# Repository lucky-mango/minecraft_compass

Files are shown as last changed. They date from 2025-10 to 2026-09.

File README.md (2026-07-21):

# Minecraft Compass — Digital Build

This repo documents my journey building a digital compass inspired by Minecraft, using an LED matrix PCB inside a custom 3D-printed enclosure.

## Preview

### FreeCAD design

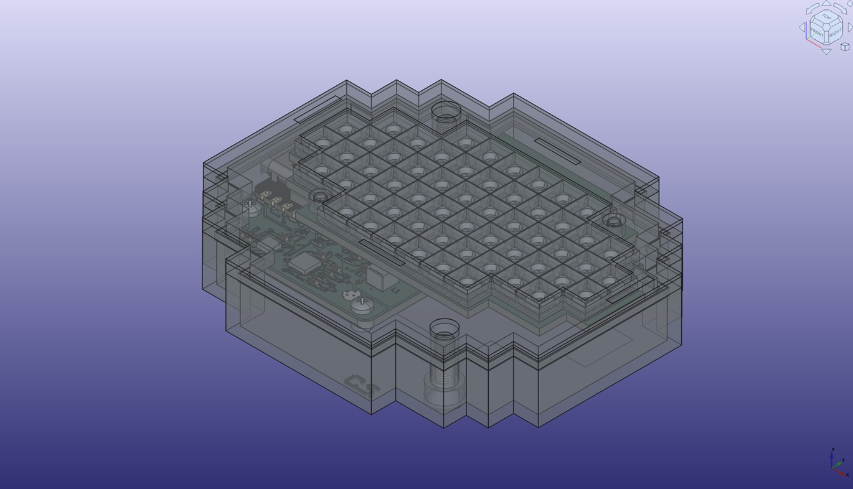
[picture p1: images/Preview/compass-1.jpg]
compass-1

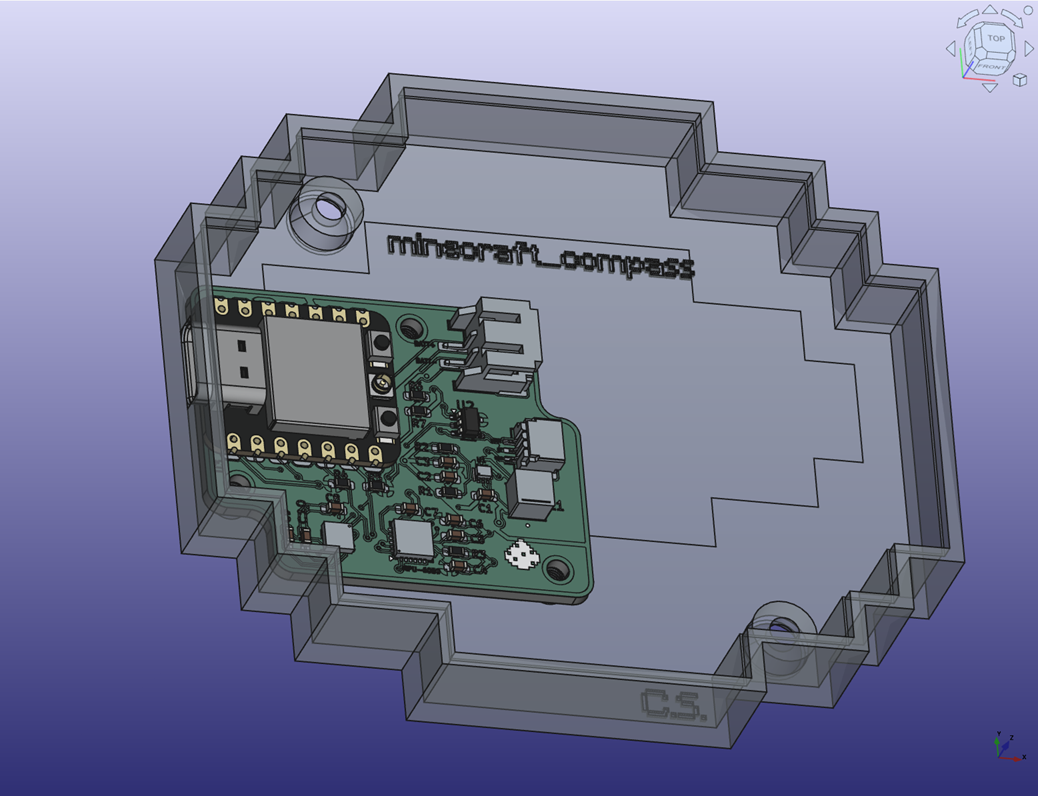
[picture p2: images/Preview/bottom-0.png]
bottom-0

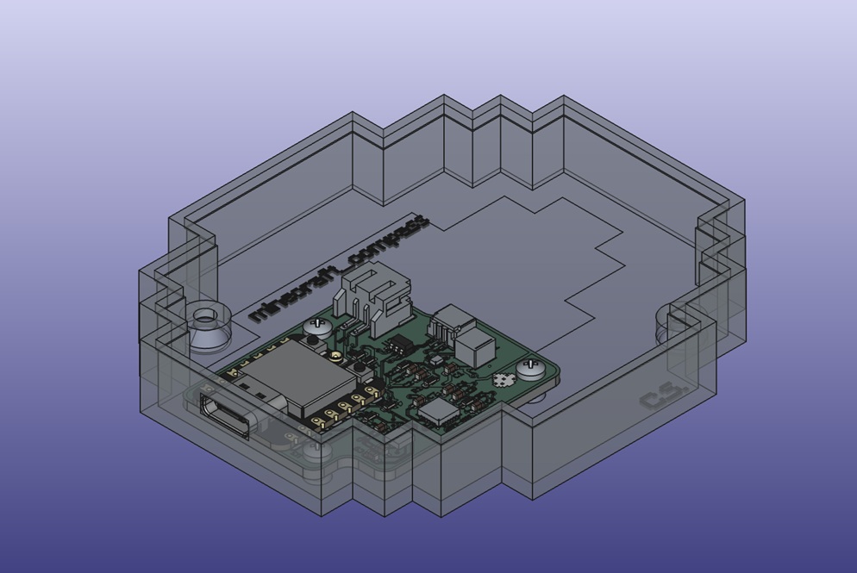
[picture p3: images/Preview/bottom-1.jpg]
bottom-1

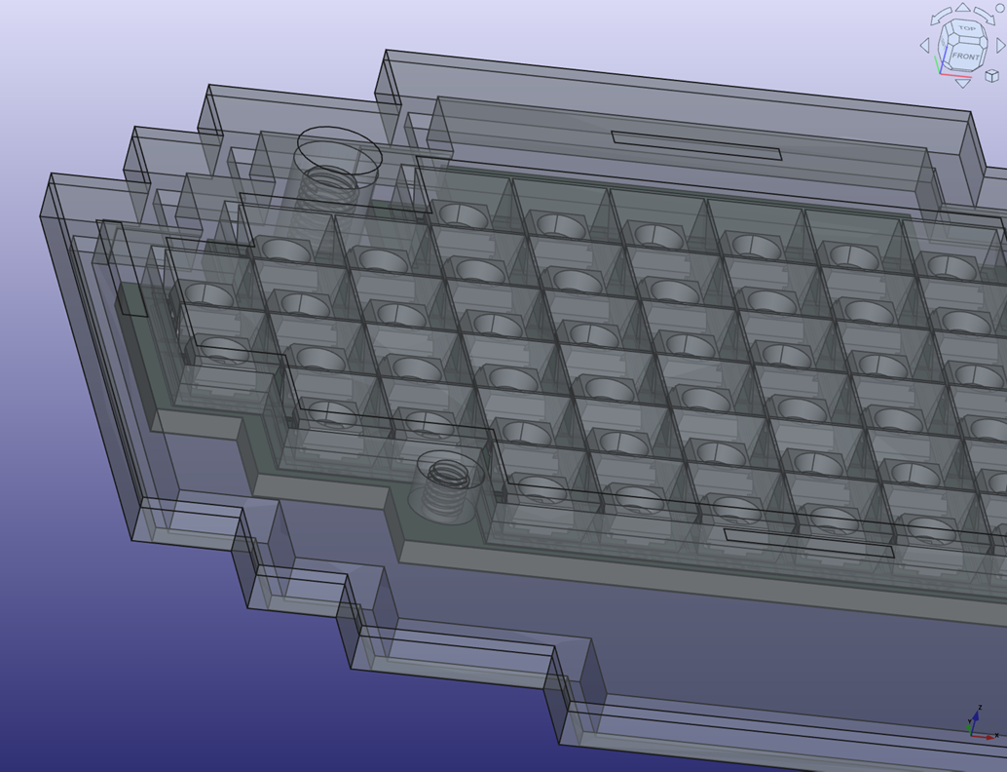
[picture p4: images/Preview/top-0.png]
top-0


### KiCAD design

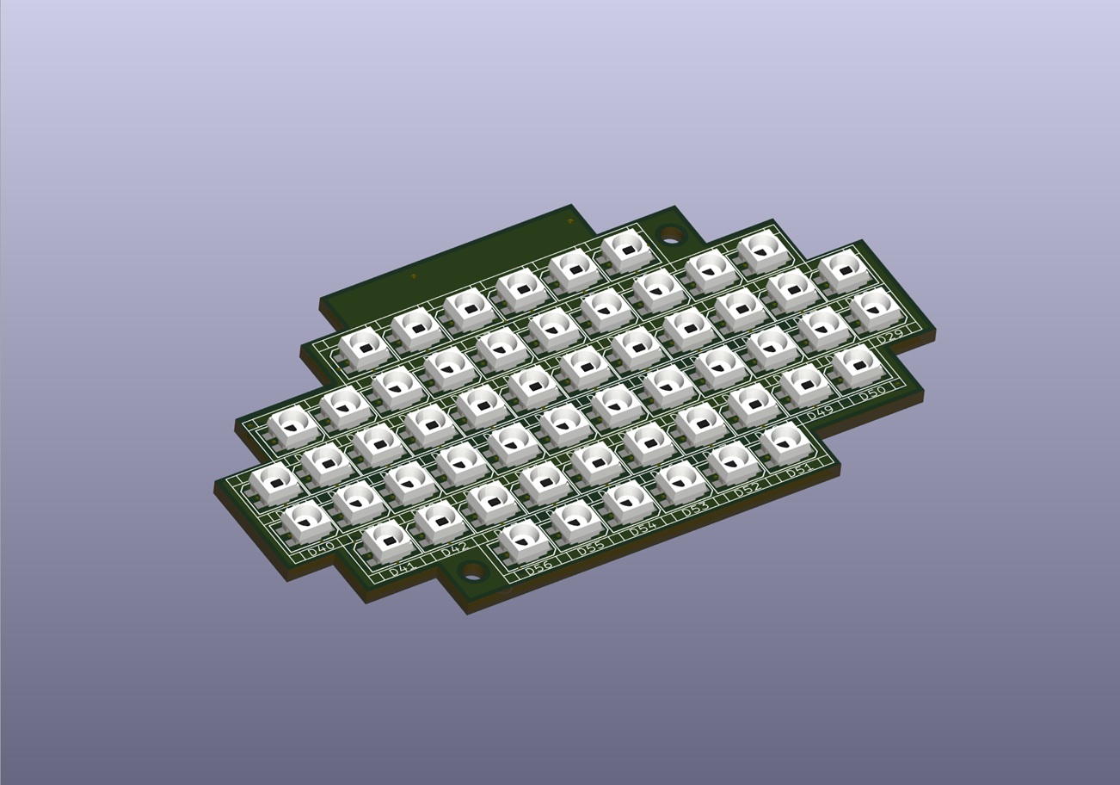
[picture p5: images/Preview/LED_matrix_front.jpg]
LED_matrix_front

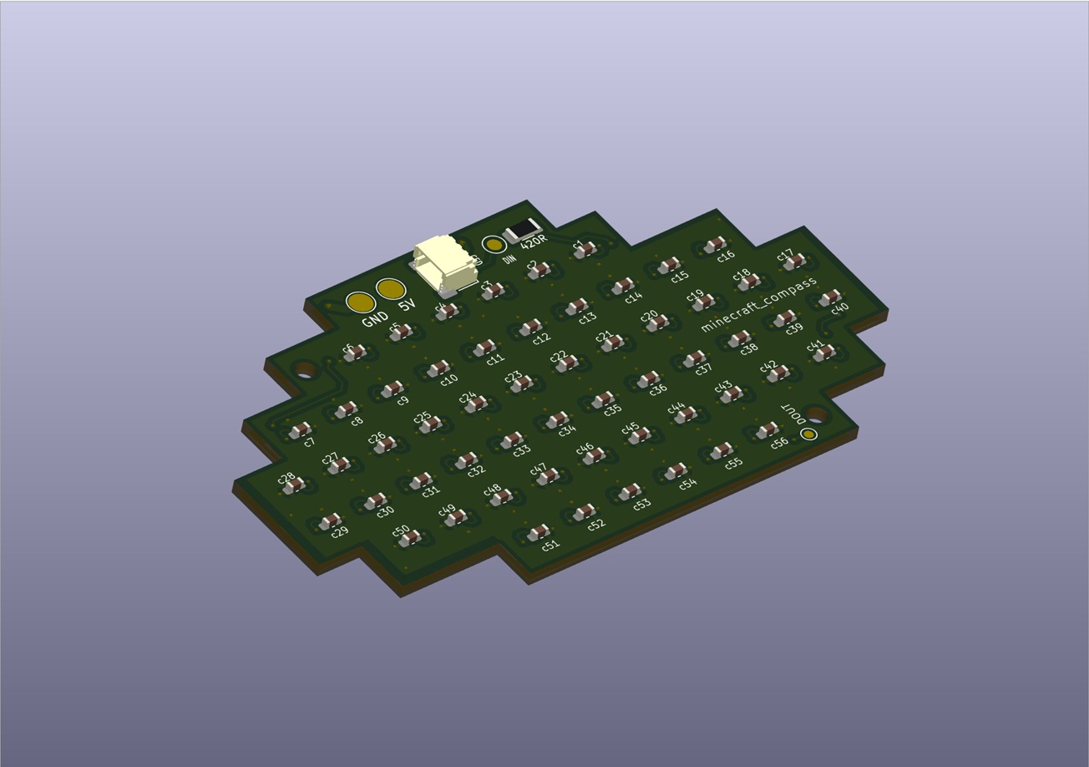
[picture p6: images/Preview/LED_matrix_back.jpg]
LED_matrix_back

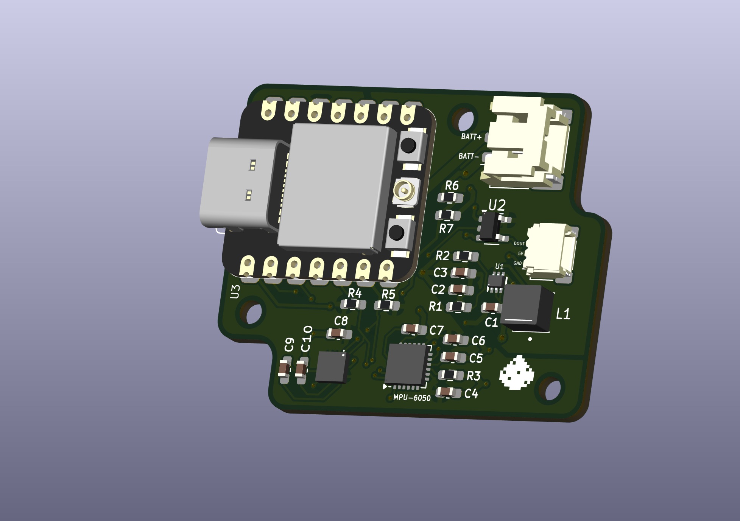
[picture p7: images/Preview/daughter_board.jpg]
daughter_board


## Repository Structure

| Path | Contents |
| --- | --- |
| `STL/` | 3D-printable enclosure files. Subdirectories (`ver1`–`ver9`) track design iterations; the latest is in `STL/ver9/`. |
| `KiCAD/Clone-new_ledMatrix/` | Current KiCAD PCB project (schematic, layout, and Gerber exports). |
| `KiCAD/new_ledMatrix/` | Earlier KiCAD project kept for reference. |
| `FreeCAD/` | FreeCAD source models for the enclosure. |
| `PCB/` | Fabrication-ready Gerber ZIP files for ordering the PCB. |
| `test_code/` | Firmware and animation test sketches. |
| `datasheets/` | Component datasheets (e.g. WS2812B-MINI LED). |
| `images/` | Project screenshots and reference images. |

## 3D Printing the Enclosure

The current STL files are in [`STL/ver9/`](STL/ver9/). Import them into your slicer (e.g. PrusaSlicer or Cura) and print as-is — no supports should be required.

## Prior Design Iterations

All previous versions of every file are preserved in Git history. Browse the [commit history](../../commits/main) on GitHub or run `git log` locally to find and restore any earlier iteration.

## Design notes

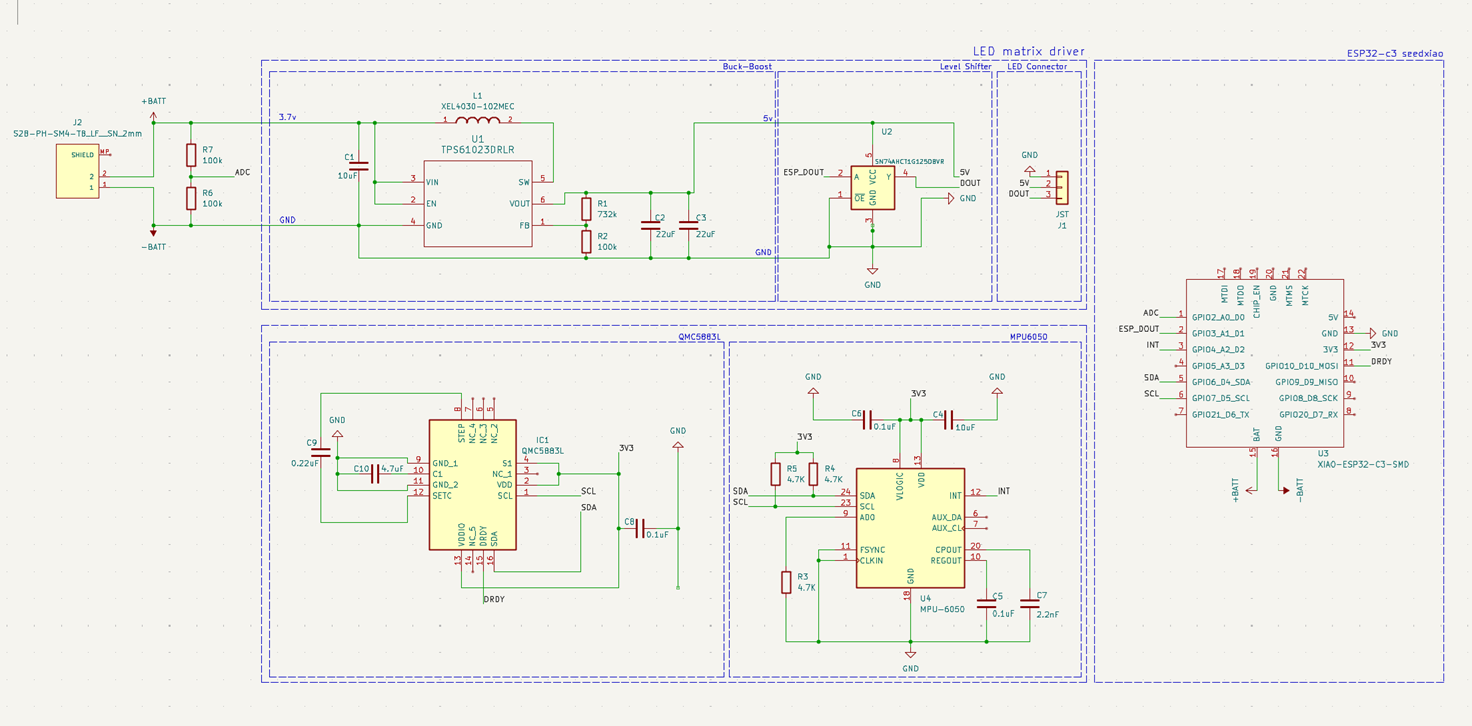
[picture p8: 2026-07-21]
images/Preview/schematic.png

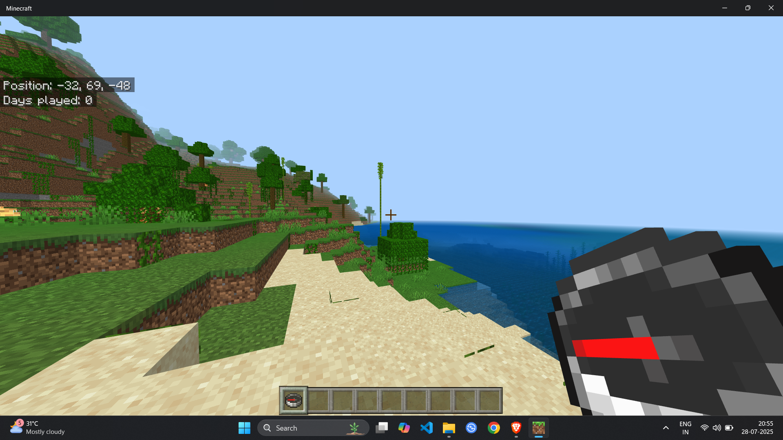
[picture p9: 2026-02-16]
images/inGame/Screenshot (229).png

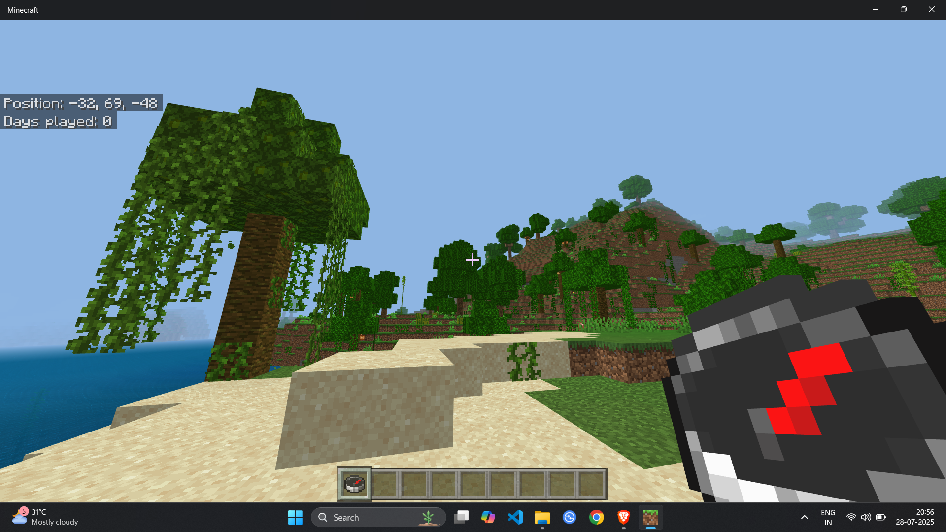
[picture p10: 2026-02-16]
images/inGame/Screenshot (245).png

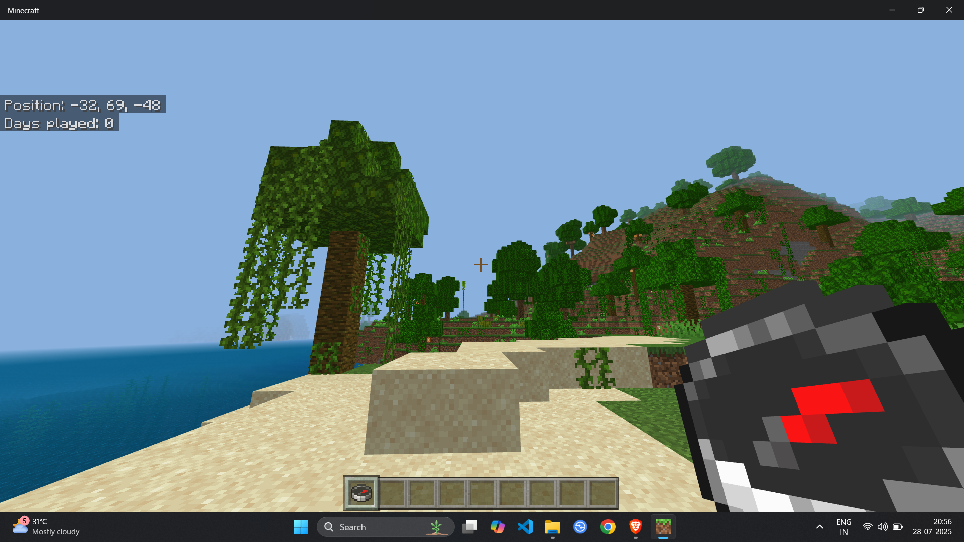
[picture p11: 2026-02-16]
images/inGame/Screenshot (244).png

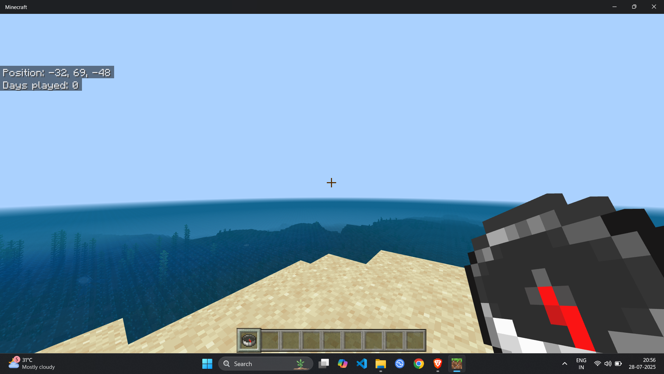
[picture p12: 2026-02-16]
images/inGame/Screenshot (236).png

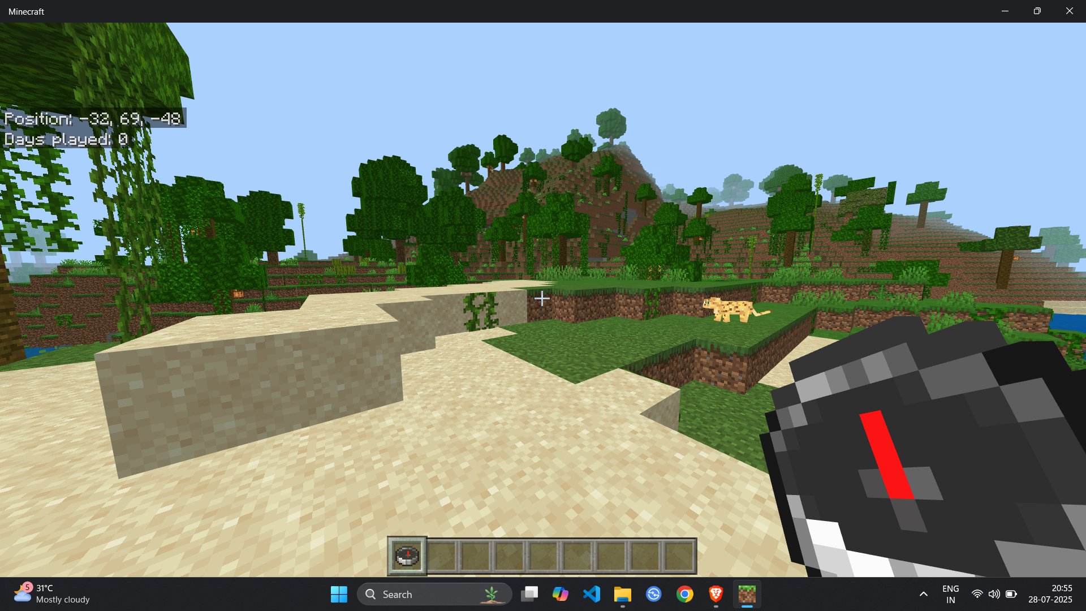
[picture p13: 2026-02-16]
images/inGame/Screenshot (222).png

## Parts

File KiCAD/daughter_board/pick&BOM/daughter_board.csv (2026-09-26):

SKU | MPN | Qty | Footprint | Reference | Value | DNP | Exclude from BOM | Exclude from Board | Datasheet
162123 |  | 1 | Sensor_Motion:InvenSense_QFN-24_4x4mm_P0.5mm_NoMask | U4 | MPU-6050 |  |  |  | https://invensense.tdk.com/wp-content/uploads/2015/02/MPU-6000-Datasheet1.pdf
 |  | 1 | My_Custom_Footprints:XIAO-ESP32C3-SMD | U3 | XIAO-ESP32-C3-SMD
R201770 | SN74AHCT1G125DBVR | 1 | Package_TO_SOT_SMD:SOT-23-5 | U2 | SN74AHCT1G125DBVR |  |  |  | https://www.onsemi.com/pdf/datasheet/nc7sz125-d.pdf
R216425 | TPS61023DRLR | 1 | custom_lib:TPS61023DRLR | U1 | TPS61023DRLR |  |  |  | https://www.ti.com/lit/gpn/tps61023
R209018 | CRCW0603100KFKEAC. | 1 | Resistor_SMD:R_0603_1608Metric | R7 | 100k |  |  |  | ~
R209018 | CRCW0603100KFKEAC | 1 | Resistor_SMD:R_0603_1608Metric | R6 | 100k |  |  |  | ~
573846 |  | 1 | Resistor_SMD:R_0603_1608Metric | R5 | 4.7K |  |  |  | ~
573846 |  | 1 | Resistor_SMD:R_0603_1608Metric | R4 | 4.7K |  |  |  | ~
573846 |  | 1 | Resistor_SMD:R_0603_1608Metric | R3 | 4.7K |  |  |  | ~
R209018 | CRCW0603100KFKEAC | 1 | Resistor_SMD:R_0603_1608Metric | R2 | 100k |  |  |  | ~
R197181 | RC0603FR-07732KL | 1 | Resistor_SMD:R_0603_1608Metric | R1 | 732k |  |  |  | ~
R113961 | XFL4020-222MEC | 1 | custom_lib:IND_XEL4030-102MEC | L1 | XEL4030-102MEC
R136185 | WT100EW-02-0-T-00 | 1 |  | J3 | SM02B-SRSS-TB_LF__SN_
R136189 | WT100EL-03-T-00 | 1 | Connector_JST:JST_SH_SM03B-SRSS-TB_1x03-1MP_P1.00mm_Horizontal | J1 | JST |  |  |  | ~
 | QMC5883L | 1 | custom_lib:QMC5883L | IC1 | QMC5883L |  |  |  | https://datasheet.lcsc.com/lcsc/2012221837_QST-QMC5883L_C976032.pdf
R144123 | CL10A475MA8NQNC | 1 | Capacitor_SMD:C_0603_1608Metric | C10 | 4.7uF |  |  |  | ~
R144018 | GRM155R71C224MA12D | 1 | Capacitor_SMD:C_0603_1608Metric | C9 | 0.22uF |  |  |  | ~
1415725 |  | 1 | Capacitor_SMD:C_0603_1608Metric | C8 | 0.1uF |  |  |  | ~
R207408 | 0603B222K500NT | 1 | Capacitor_SMD:C_0603_1608Metric | C7 | 2.2nF |  |  |  | ~
1415725 |  | 1 | Capacitor_SMD:C_0603_1608Metric | C6 | 0.1uF |  |  |  | ~
1415725 |  | 1 | Capacitor_SMD:C_0603_1608Metric | C5 | 0.1uF |  |  |  | ~
R144118 | 0603X106K160NT | 1 | Capacitor_SMD:C_0603_1608Metric | C4 | 10uF |  |  |  | ~
R243185 | CL10A226MO7JZNC | 1 | Capacitor_SMD:C_0603_1608Metric | C3 | 22uF |  |  |  | ~
R243185 | CL10A226MO7JZNC | 1 | Capacitor_SMD:C_0603_1608Metric | C2 | 22uF |  |  |  | ~
R144118 | 0603X106K160NT | 1 | Capacitor_SMD:C_0603_1608Metric | C1 | 10uF |  |  |  | ~

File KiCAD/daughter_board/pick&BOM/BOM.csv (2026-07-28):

Id | Designator | Footprint | Quantity | Designation | Supplier and ref
1 | U2 | SOT-23-5 | 1 | SN74AHCT1G125DBVR
2 | U1 | TPS61023DRLR | 1 | TPS61023DRLR
3 | U3 | XIAO-ESP32C3-SMD | 1 | XIAO-ESP32-C3-SMD
4 | C6,C8,C5 | C_0603_1608Metric_Pad1.08x0.95mm_HandSolder | 3 | 0.1uF
5 | R2,R7,R6 | R_0603_1608Metric_Pad0.98x0.95mm_HandSolder | 3 | 100k
6 | 0.8mm | Castellated_Hole_0.8mm | 1 | Castellated_Hole_0.8mm
7 | C1,C4 | C_0603_1608Metric_Pad1.08x0.95mm_HandSolder | 2 | 10uF
8 | J1 | JST_SH_SM03B-SRSS-TB_1x03-1MP_P1.00mm_Horizontal | 1 | JST
9 | C3,C2 | C_0603_1608Metric_Pad1.08x0.95mm_HandSolder | 2 | 22uF
10 | R5,R3,R4 | R_0603_1608Metric_Pad0.98x0.95mm_HandSolder | 3 | 4.7K
11 | C10 | C_0603_1608Metric_Pad1.08x0.95mm_HandSolder | 1 | 4.7uF
12 | R1 | R_0603_1608Metric_Pad0.98x0.95mm_HandSolder | 1 | 732k
13 | L1 | IND_XEL4030-102MEC | 1 | XEL4030-102MEC
14 | C9 | C_0603_1608Metric_Pad1.08x0.95mm_HandSolder | 1 | 0.22uF
15 | U4 | InvenSense_QFN-24_4x4mm_P0.5mm_NoMask | 1 | MPU-6050
16 | J2 | JST_PH_S2B-PH-SM4-TB_1x02-1MP_P2.00mm_Horizontal | 1 | S2B-PH-SM4-TB_LF__SN_2mm
17 | IC1 | QMC5883L | 1 | QMC5883L
18 |  |  | 1
19 | C7 | C_0603_1608Metric_Pad1.08x0.95mm_HandSolder | 1 | 2.2nF

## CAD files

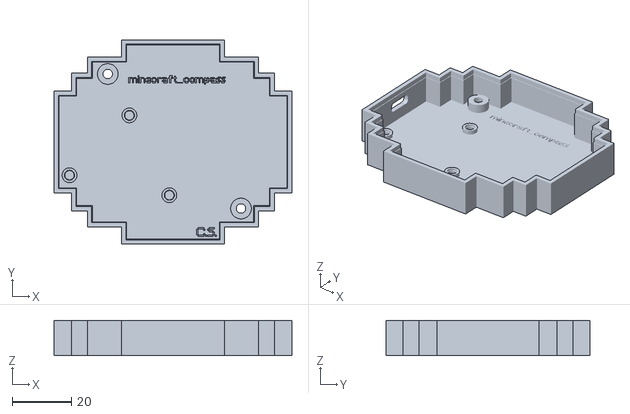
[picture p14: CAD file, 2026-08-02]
3D_models/compass_case/minecraftCompassVer.4-bottom_plate(lowered_daughterBoard,heatinserts-2mm_deep).stl
80.5 x 69.1 x 12.0

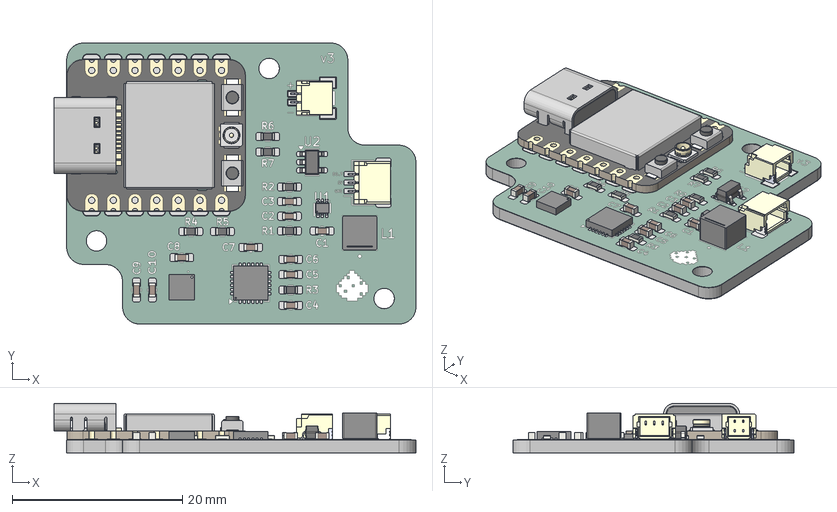
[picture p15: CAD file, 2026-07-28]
3D_models/daughter_board-v3.step
42.5 x 33.0 x 5.88 mm
SOT-23-5
TPS61023DRLR
BOSS-EXTRUDE14_8_
BOSS-EXTRUDE7_4_
BOSS-EXTRUDE7_3_
BOSS-EXTRUDE14_4_
BOSS-EXTRUDE14_2_
BOSS-EXTRUDE14_11_
BOSS-EXTRUDE7_7_
BOSS-EXTRUDE14_9_
BOSS-EXTRUDE14_3_
BOSS-EXTRUDE14_7_
MIRROR2
BOSS-EXTRUDE14_5_
BOSS-EXTRUDE14_12_
BOSS-EXTRUDE7_8_
BOSS-EXTRUDE7_1_
BOSS-EXTRUDE14_10_
BOSS-EXTRUDE7_9_
BOSS-EXTRUDE14_6_
BOSS-EXTRUDE14_1_
BOSS-EXTRUDE7_6_
BOSS-EXTRUDE7_2_
CUT-EXTRUDE5
BOSS-EXTRUDE7_5_
U.FL Connector v1
Button (1) x 2
Shield
C_0603_1608Metric x 10
R_0603_1608Metric x 7
SM03B-SRSS-TB (LF)(SN)
SM02B-SRSS-TB_LF__SN_
XEL4030-102MEC--3DModel-STEP-269445
MPU-6050C
HMC5883L-TR
daughter_board_copper
daughter_board_pad
daughter_board_via
daughter_board_silkscreen
daughter_board_soldermask
daughter_board_PCB

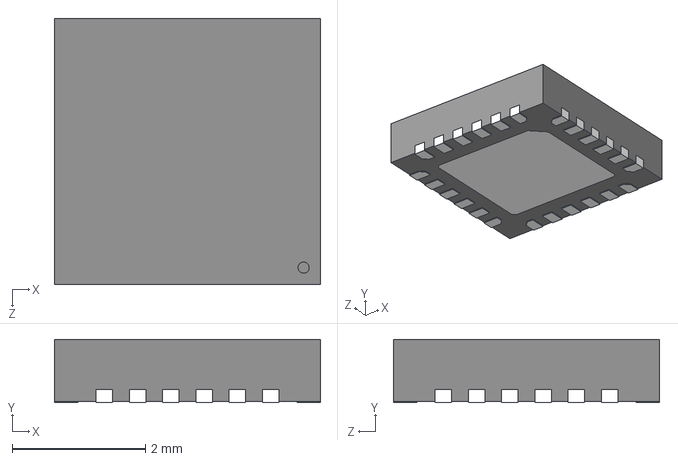
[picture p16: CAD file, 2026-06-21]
3D_models/mpu6050-8.snapshot.1/MPU-6050C.STEP
4.00 x 0.95 x 4.00 mm

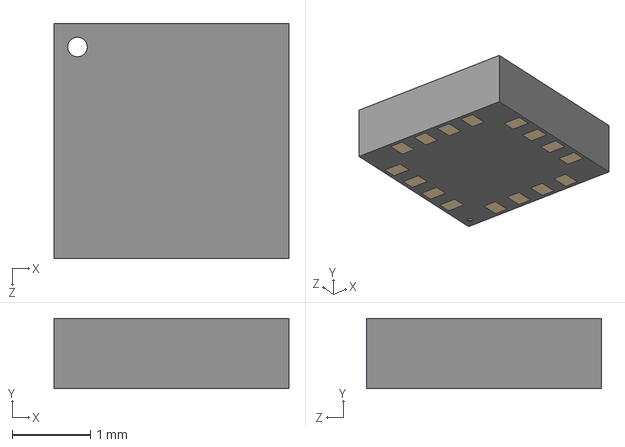
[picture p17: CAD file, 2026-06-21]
3D_models/QMC5883L/3D/HMC5883L-TR.STEP
3.00 x 0.9 x 3.00 mm

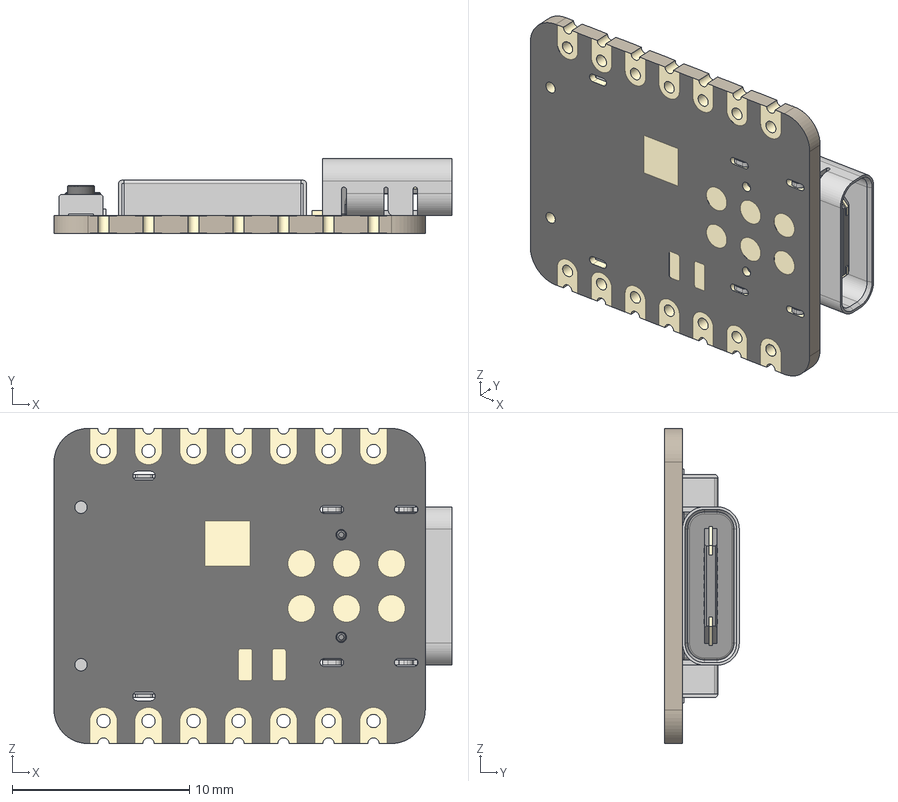
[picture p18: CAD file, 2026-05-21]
3D_models/seeed-studio-xiao-esp32-c3-1.snapshot.8 (1)/Seeed Studio XIAO-ESP32-C3.step
22.5 x 4.21 x 17.8 mm
BOSS-EXTRUDE14_8_
BOSS-EXTRUDE7_4_
BOSS-EXTRUDE7_3_
BOSS-EXTRUDE14_4_
BOSS-EXTRUDE14_2_
BOSS-EXTRUDE14_11_
BOSS-EXTRUDE7_7_
BOSS-EXTRUDE14_9_
BOSS-EXTRUDE14_3_
BOSS-EXTRUDE14_7_
MIRROR2
BOSS-EXTRUDE14_5_
BOSS-EXTRUDE14_12_
BOSS-EXTRUDE7_8_
BOSS-EXTRUDE7_1_
BOSS-EXTRUDE14_10_
BOSS-EXTRUDE7_9_
BOSS-EXTRUDE14_6_
BOSS-EXTRUDE14_1_
BOSS-EXTRUDE7_6_
BOSS-EXTRUDE7_2_
CUT-EXTRUDE5
BOSS-EXTRUDE7_5_
U.FL Connector v1
Button (1) x 2
Shield

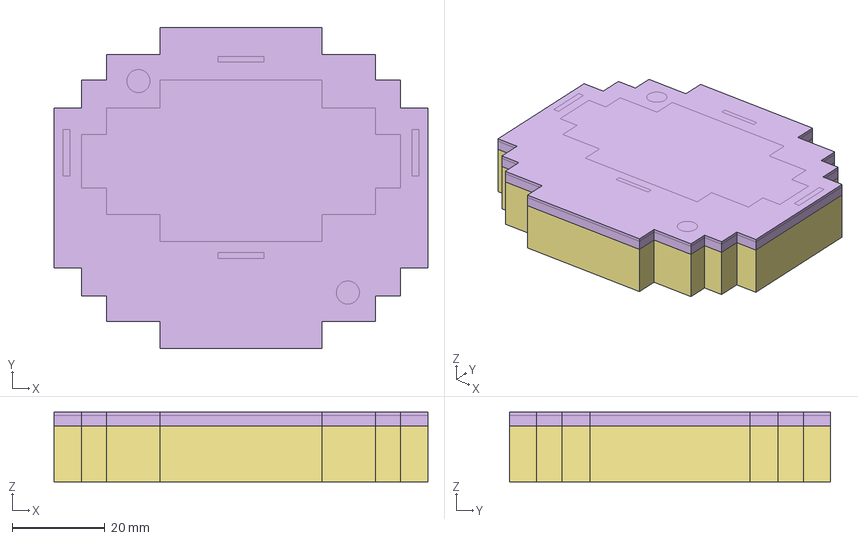
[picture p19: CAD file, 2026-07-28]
FreeCAD/minecraftCompassVer.4.FCStd
80.5 x 69.1 x 15.0 mm
M2x4-Screw001
M2x4-Screw
M2x3-Screw050
M2x3-Screw049
M2x3-Screw
top_plate
bottom_plate
SMD WS2812B Mini
SMD WS2812B Mini001
SMD WS2812B Mini002
SMD WS2812B Mini003
SMD WS2812B Mini004
SMD WS2812B Mini005
SMD WS2812B Mini006
SMD WS2812B Mini007
SMD WS2812B Mini008
SMD WS2812B Mini009
SMD WS2812B Mini010
SMD WS2812B Mini011
SMD WS2812B Mini012
SMD WS2812B Mini013
SMD WS2812B Mini014
SMD WS2812B Mini015
SMD WS2812B Mini016
SMD WS2812B Mini017
SMD WS2812B Mini018
SMD WS2812B Mini019
SMD WS2812B Mini020
SMD WS2812B Mini021
SMD WS2812B Mini022
SMD WS2812B Mini023
SMD WS2812B Mini024
SMD WS2812B Mini025
SMD WS2812B Mini026
SMD WS2812B Mini027
SMD WS2812B Mini028
SMD WS2812B Mini029
SMD WS2812B Mini030
SMD WS2812B Mini031
SMD WS2812B Mini032
SMD WS2812B Mini033
SMD WS2812B Mini034
SMD WS2812B Mini035
SMD WS2812B Mini036
SMD WS2812B Mini037
SMD WS2812B Mini038
SMD WS2812B Mini039
SMD WS2812B Mini040
SMD WS2812B Mini041
SMD WS2812B Mini042
SMD WS2812B Mini043
SMD WS2812B Mini044
SMD WS2812B Mini045
SMD WS2812B Mini046
SMD WS2812B Mini047
SMD WS2812B Mini048
SMD WS2812B Mini049
SMD WS2812B Mini050
SMD WS2812B Mini051
SMD WS2812B Mini052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

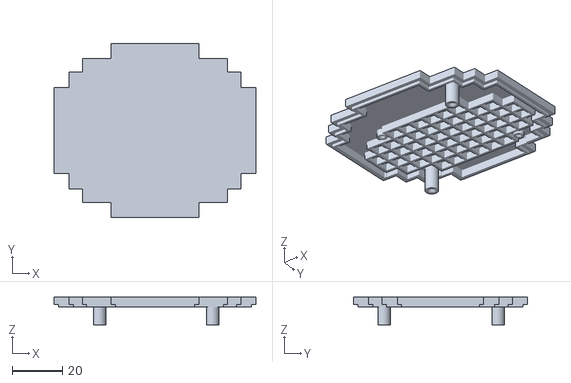
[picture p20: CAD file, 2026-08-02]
3D_models/compass_case/minecraftCompassVer.4-bottom_plate(4mm_gridBezzel).stl
80.5 x 69.1 x 11.0

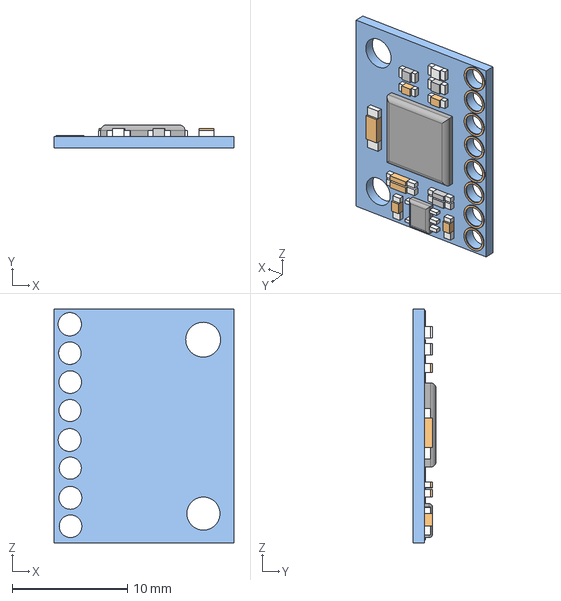
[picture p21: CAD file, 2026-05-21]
3D_models/mpu6050-8.snapshot.1/MPU6050 v2.step
15.6 x 2.00 x 20.3 mm

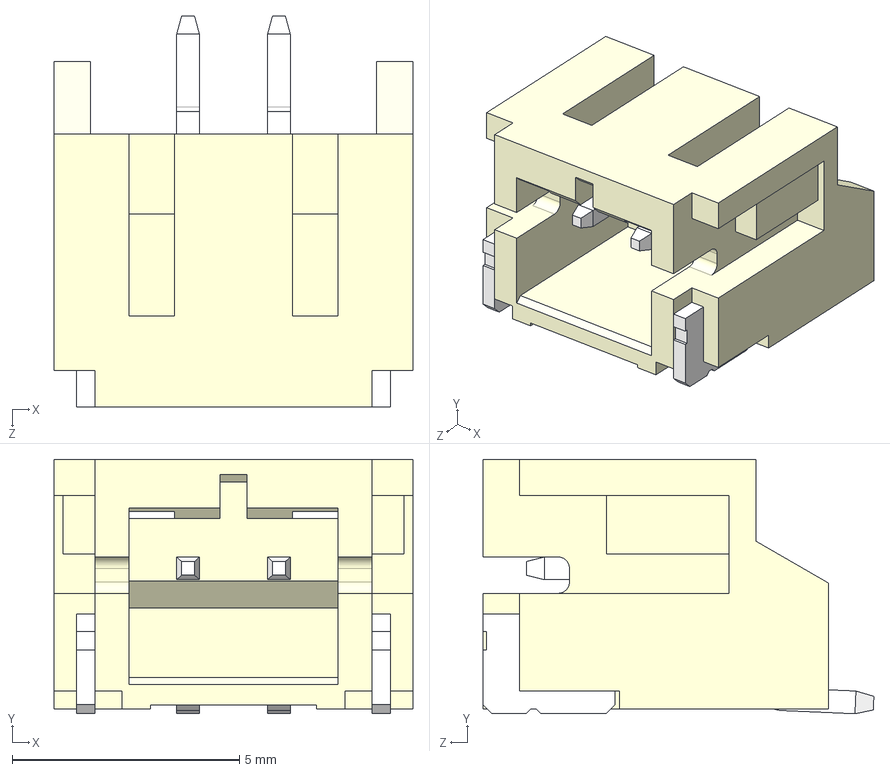
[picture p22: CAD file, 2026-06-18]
3D_models/JST_PH_S2B-PH-SM4-TB_1x02-1MP_P2.00mm_Horizontal.step
7.90 x 5.60 x 8.60 mm

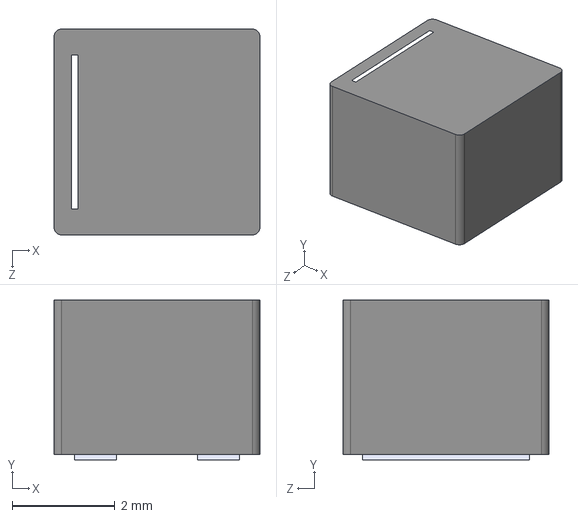
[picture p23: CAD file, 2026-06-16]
3D_models/XEL4030-102MEC--3DModel-STEP-269445.STEP
4.00 x 3.10 x 4.00 mm

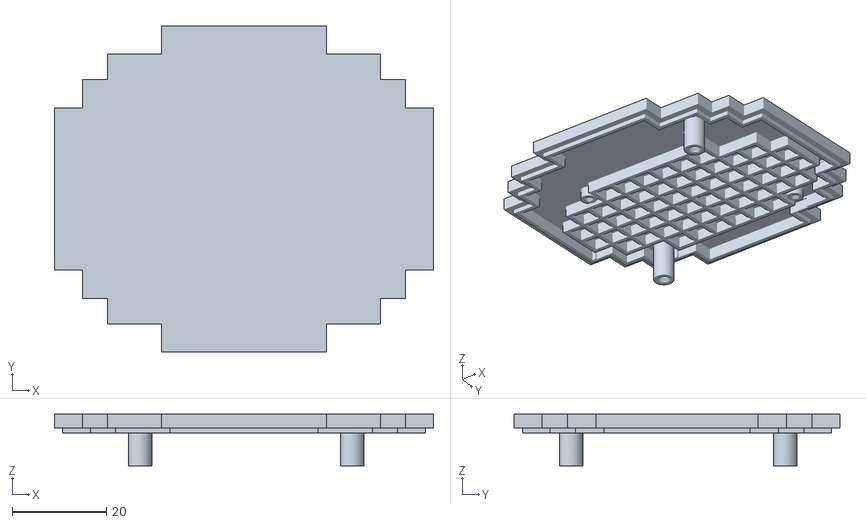
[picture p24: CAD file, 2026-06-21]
3D_models/compass_case/minecraftCompassVer.4-top_plate.stl
80.5 x 69.1 x 11.0

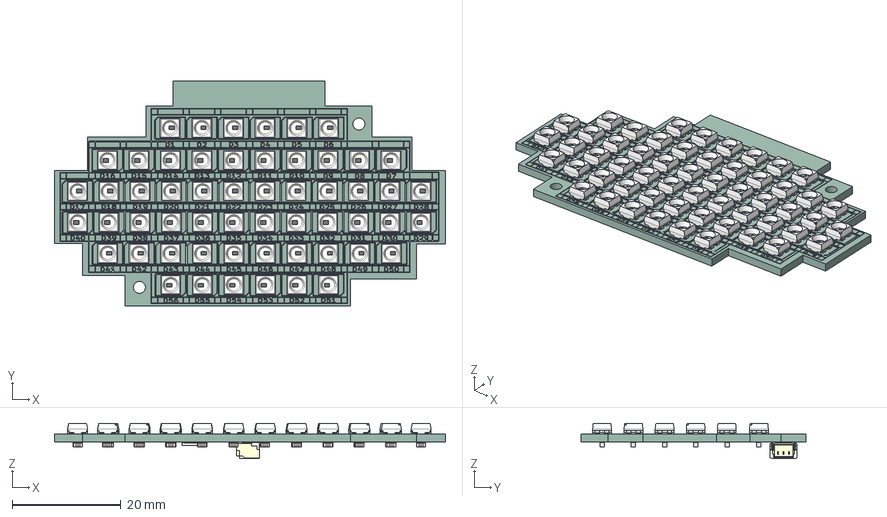
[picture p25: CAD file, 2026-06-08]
3D_models/LED_matrix_ver7.step
72.1 x 41.4 x 6.54 mm
SMD WS2812B Mini x 56
C_0603_1608Metric x 56
R_1206_3216Metric
SM03B-SRSS-TB (LF)(SN)
new_ledMatrix_silkscreen
new_ledMatrix_PCB

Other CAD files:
FreeCAD/assembly.FCStd
3D_models/compass_case/minecraftCompassVer.4-bottom_plate(heat_inserts of m2x2mm,OD-3.1mm).stl
3D_models/compass_case/minecraftCompassVer.4-bottom_plate(heat_inserts of m2x2mm).stl
3D_models/compass_case/minecraftCompassVer.4-bottom_plate.stl
3D_models/compass_case/minecraftCompassVer.4-top_plate(resin_print,0.5mm led screen thickness).stl
3D_models/QMC5883L/Allegro/qmc5883l.psm
3D_models/QMC5883L/DEHDL/qmc5883l/chips/chips.prt
3D_models/SM03B-SRSS-TB (LF)(SN).STEP
3D_models/SMD WS2812B Mini.step
3D_models/TPS61023DRLR.STEP
3D_models/daughter_board-v2.step
3D_models/mpu6050-8.snapshot.1/MPU6050 v2.stl

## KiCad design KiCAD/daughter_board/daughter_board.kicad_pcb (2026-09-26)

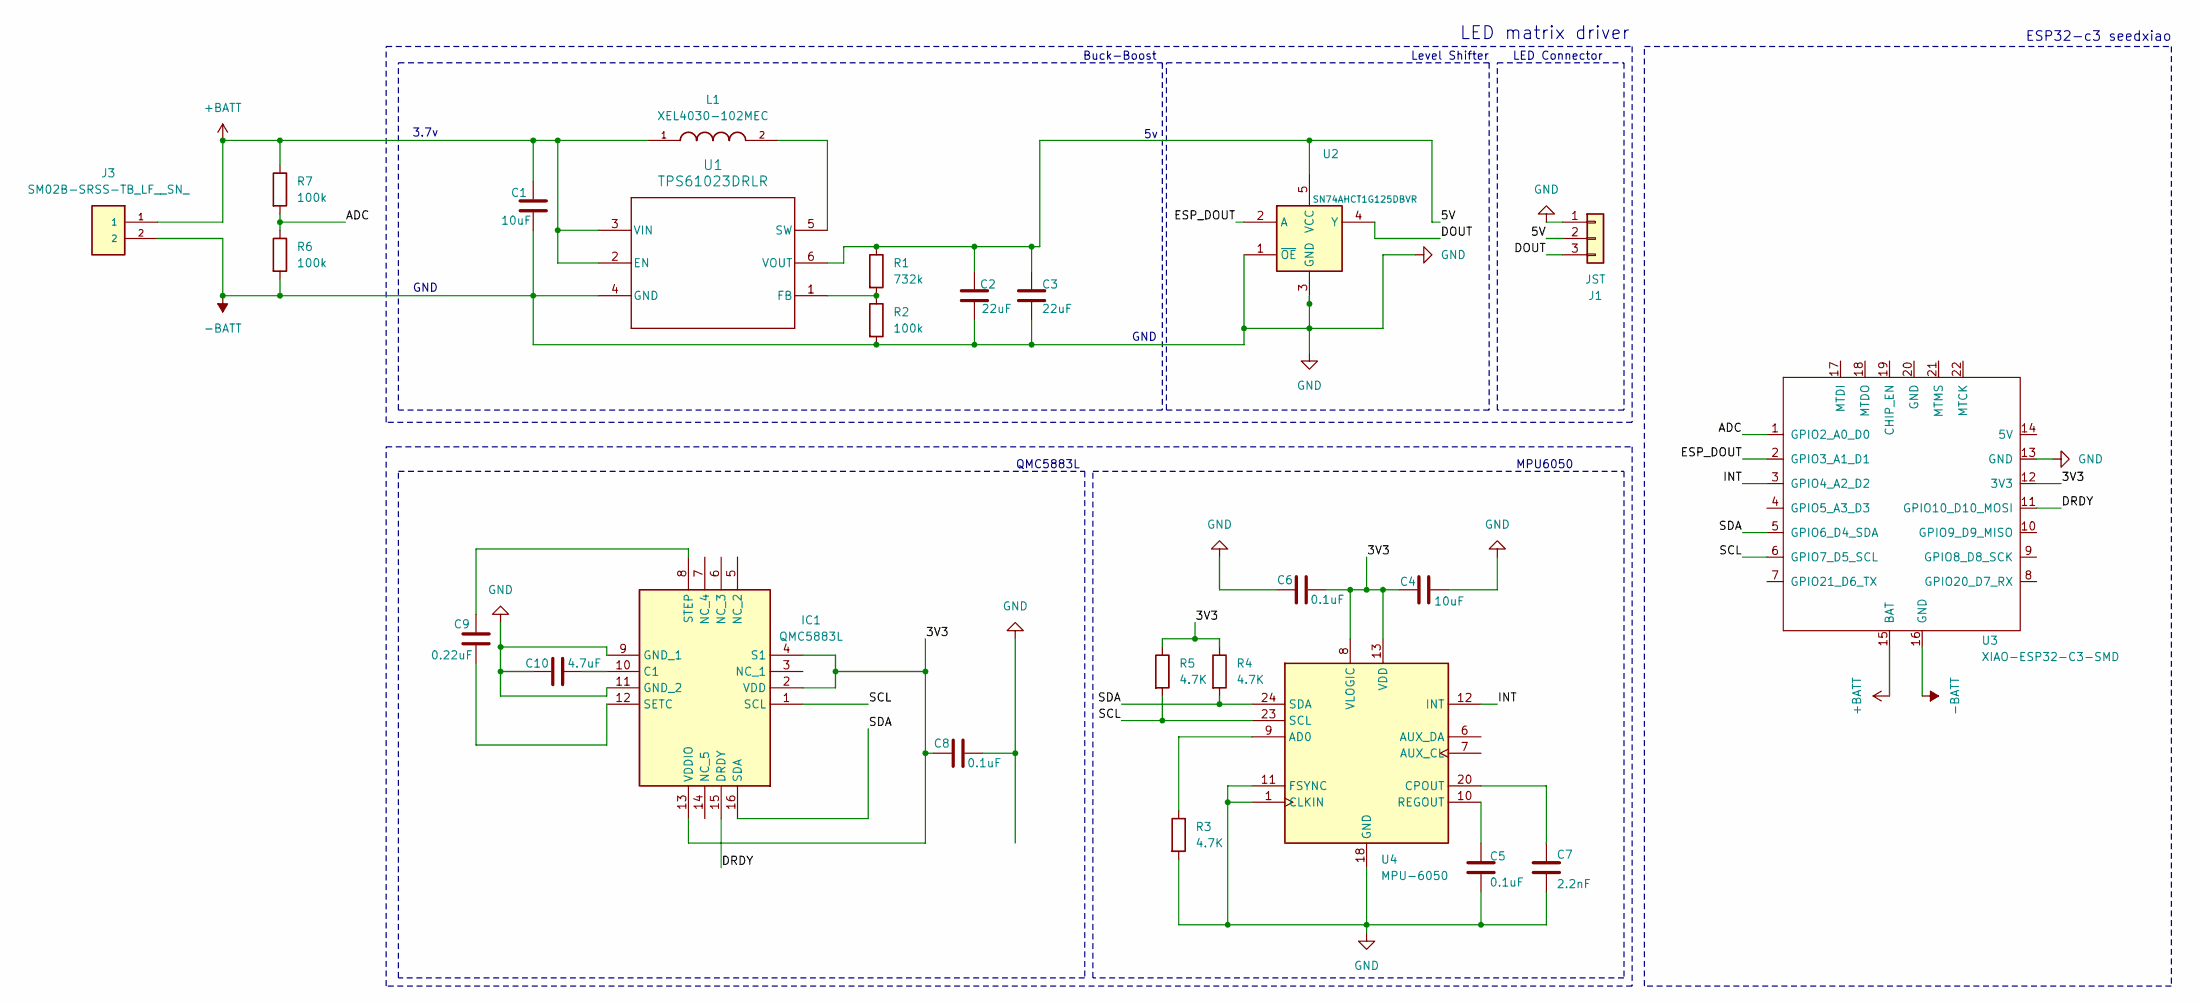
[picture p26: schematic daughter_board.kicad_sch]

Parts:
C1, C4: 10uF; C_0603_1608Metric; MPN 0603X106K160NT
C2, C3: 22uF; C_0603_1608Metric; MPN CL10A226MO7JZNC
C5, C6, C8: 0.1uF; C_0603_1608Metric
C7: 2.2nF; C_0603_1608Metric; MPN 0603B222K500NT
C9: 0.22uF; C_0603_1608Metric; MPN GRM155R71C224MA12D
C10: 4.7uF; C_0603_1608Metric; MPN CL10A475MA8NQNC
IC1: QMC5883L; MPN QMC5883L
J1: JST; JST_SH_SM03B-SRSS-TB_1x03-1MP_P1.00mm_Horizontal; MPN WT100EL-03-T-00
J3: SM02B-SRSS-TB_LF__SN_; MPN WT100EW-02-0-T-00
L1: XEL4030-102MEC; IND_XEL4030-102MEC; PARTREV 05/10/24
R1: 732k; R_0603_1608Metric; MPN RC0603FR-07732KL
R2, R6: 100k; R_0603_1608Metric; MPN CRCW0603100KFKEAC
R3, R4, R5: 4.7K; R_0603_1608Metric
R7: 100k; R_0603_1608Metric; MPN CRCW0603100KFKEAC.
U1: TPS61023DRLR; MPN TPS61023DRLR
U2: SN74AHCT1G125DBVR; SOT-23-5; MPN SN74AHCT1G125DBVR
U3: XIAO-ESP32-C3-SMD; XIAO-ESP32C3-SMD
U4: MPU-6050; InvenSense_QFN-24_4x4mm_P0.5mm_NoMask

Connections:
+BATT: C1.1, J3.1, L1.1, R7.1, U1.2 (EN), U1.3 (VIN), U3.15 (BAT)
-BATT: C1.2, C2.2, C3.2, C4.1, C5.2, C6.2, C7.2, C8.1, C10.2, IC1.9 (GND_1), IC1.11 (GND_2), J1.1, J3.2, R2.2, R3.2, R6.2, U1.4 (GND), U2.1 (~OE), U2.3 (GND), U3.13 (GND), U3.16 (GND), U4.1 (CLKIN), U4.11 (FSYNC), U4.18 (GND); also elsewhere on the board
/3V3: C4.2, C6.1, C8.2, IC1.2 (VDD), IC1.4 (S1), IC1.13 (VDDIO), R4.1, R5.1, U3.12 (3V3), U4.8 (VLOGIC), U4.13 (VDD)
/5V: C2.1, C3.1, J1.2, R1.1, U1.6 (VOUT), U2.5 (VCC)
/ADC: R6.1, R7.2, U3.1 (GPIO2_A0_D0)
/DOUT: J1.3, U2.4 (Y)
/DRDY: IC1.15 (DRDY), U3.11 (GPIO10_D10_MOSI)
/ESP_DOUT: U2.2 (A), U3.2 (GPIO3_A1_D1)
/INT: U3.3 (GPIO4_A2_D2), U4.12 (INT)
/SCL: IC1.1 (SCL), R5.2, U3.6 (GPIO7_D5_SCL), U4.23 (SCL)
/SDA: IC1.16 (SDA), R4.2, U3.5 (GPIO6_D4_SDA), U4.24 (SDA)
unnamed: C10.1, IC1.10 (C1)
unnamed: C9.1, IC1.12 (SETC)
unnamed: C9.2, IC1.8 (STEP)
unnamed: R1.2, R2.1, U1.1 (FB)
unnamed: L1.2, U1.5 (SW)
unnamed: R3.1, U4.9 (AD0)
unnamed: C7.1, U4.20 (CPOUT)
unnamed: C5.1, U4.10 (REGOUT)

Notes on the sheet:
QMC5883L
MPU6050
LED matrix driver
3.7v
GND
Buck-Boost
Level Shifter
LED Connector
GND
ESP32-c3 seedxiao

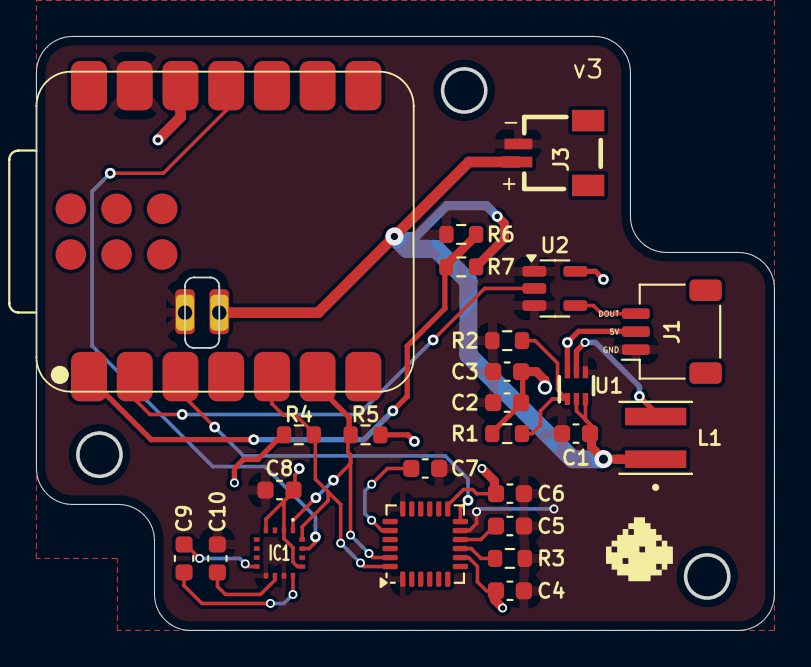
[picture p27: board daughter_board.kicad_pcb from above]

Board: 2 copper layers, 41.0 x 33.0 mm, 26 parts (0 on the bottom side), 19 nets.

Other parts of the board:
0.8mm: Castellated_Hole_0.8mm

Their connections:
-BATT: 0.8mm.1; also elsewhere on the board

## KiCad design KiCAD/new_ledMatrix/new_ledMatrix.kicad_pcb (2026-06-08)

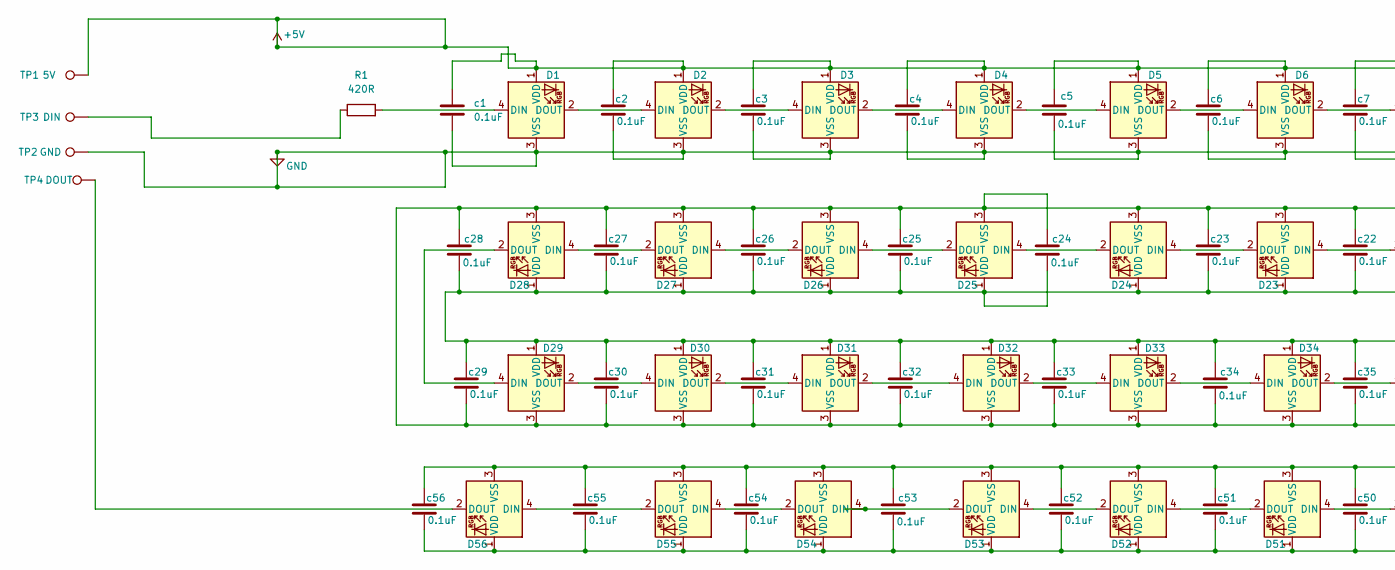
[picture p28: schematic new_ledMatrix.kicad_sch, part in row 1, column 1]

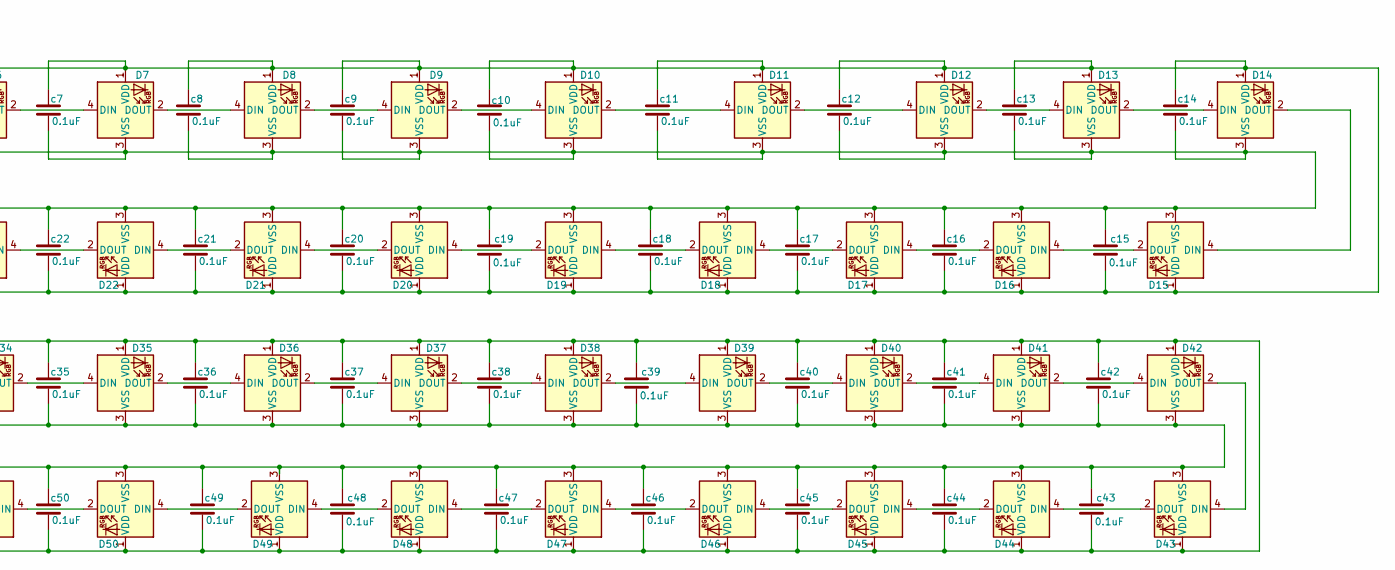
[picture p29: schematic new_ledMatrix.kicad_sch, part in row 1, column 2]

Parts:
D1, D2, D3, D4, D5, D6, D7, D8, D9, D10, D11, D12, D13, D14, D15, D16, D17, D18, D19, D20, D21, D22, D23, D24, D25, D26, D27, D28, D29, D30, D31, D32, D33, D34, D35, D36, D37, D38, D39, D40, D41, D42, D43, D44, D45, D46, D47, D48, D49, D50, D51, D52, D53, D54, D55, D56: WS2812B-Mini; LED_SK6812MINI_PLCC4_3.5x3.5mm_P1.75mm
R1: 420R; R_1206_3216Metric
TP1: 5V; TestPoint_Pad_D2.5mm
TP2: GND; TestPoint_Pad_D2.5mm
TP3: DIN; TestPoint_Pad_D2.5mm
TP4: DOUT; TestPoint_Pad_D2.5mm
c1, c2, c3, c4, c5, c6, c7, c8, c9, c10, c11, c12, c13, c14, c15, c16, c17, c18, c19, c20, c21, c22, c23, c24, c25, c26, c27, c28, c29, c30, c31, c32, c33, c34, c35, c36, c37, c38, c39, c40, c41, c42, c43, c44, c45, c46, c47, c48, c49, c50, c51, c52, c53, c54, c55, c56: 0.1uF; C_0603_1608Metric

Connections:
unnamed: D1.4 (DIN), R1.2
unnamed: D1.2 (DOUT), D2.4 (DIN)
unnamed: D2.2 (DOUT), D3.4 (DIN)
unnamed: D3.2 (DOUT), D4.4 (DIN)
unnamed: D4.2 (DOUT), D5.4 (DIN)
unnamed: D5.2 (DOUT), D6.4 (DIN)
unnamed: D6.2 (DOUT), D7.4 (DIN)
unnamed: D7.2 (DOUT), D8.4 (DIN)
unnamed: D8.2 (DOUT), D9.4 (DIN)
unnamed: D9.2 (DOUT), D10.4 (DIN)
unnamed: D10.2 (DOUT), D11.4 (DIN)
unnamed: D11.2 (DOUT), D12.4 (DIN)
unnamed: D12.2 (DOUT), D13.4 (DIN)
unnamed: D13.2 (DOUT), D14.4 (DIN)
unnamed: D14.2 (DOUT), D15.4 (DIN)
unnamed: D15.2 (DOUT), D16.4 (DIN)
unnamed: D16.2 (DOUT), D17.4 (DIN)
unnamed: D17.2 (DOUT), D18.4 (DIN)
unnamed: D18.2 (DOUT), D19.4 (DIN)
unnamed: D19.2 (DOUT), D20.4 (DIN)
unnamed: D20.2 (DOUT), D21.4 (DIN)
unnamed: D21.2 (DOUT), D22.4 (DIN)
unnamed: D22.2 (DOUT), D23.4 (DIN)
unnamed: D23.2 (DOUT), D24.4 (DIN)
unnamed: D24.2 (DOUT), D25.4 (DIN)
unnamed: D25.2 (DOUT), D26.4 (DIN)
unnamed: D26.2 (DOUT), D27.4 (DIN)
unnamed: D27.2 (DOUT), D28.4 (DIN)
unnamed: D28.2 (DOUT), D29.4 (DIN)
unnamed: D29.2 (DOUT), D30.4 (DIN)
unnamed: D30.2 (DOUT), D31.4 (DIN)
unnamed: D31.2 (DOUT), D32.4 (DIN)
unnamed: D32.2 (DOUT), D33.4 (DIN)
unnamed: D33.2 (DOUT), D34.4 (DIN)
unnamed: D34.2 (DOUT), D35.4 (DIN)
unnamed: D35.2 (DOUT), D36.4 (DIN)
unnamed: D36.2 (DOUT), D37.4 (DIN)
unnamed: D37.2 (DOUT), D38.4 (DIN)
unnamed: D38.2 (DOUT), D39.4 (DIN)
unnamed: D39.2 (DOUT), D40.4 (DIN)
unnamed: D40.2 (DOUT), D41.4 (DIN)
unnamed: D41.2 (DOUT), D42.4 (DIN)
unnamed: D42.2 (DOUT), D43.4 (DIN)
unnamed: D43.2 (DOUT), D44.4 (DIN)
unnamed: D44.2 (DOUT), D45.4 (DIN)
unnamed: D45.2 (DOUT), D46.4 (DIN)
unnamed: D46.2 (DOUT), D47.4 (DIN)
unnamed: D47.2 (DOUT), D48.4 (DIN)
unnamed: D48.2 (DOUT), D49.4 (DIN)
unnamed: D49.2 (DOUT), D50.4 (DIN)
unnamed: D50.2 (DOUT), D51.4 (DIN)
unnamed: D51.2 (DOUT), D52.4 (DIN)
unnamed: D52.2 (DOUT), D53.4 (DIN)
unnamed: D53.2 (DOUT), D54.4 (DIN)
unnamed: D54.2 (DOUT), D55.4 (DIN)
unnamed: D55.2 (DOUT), D56.4 (DIN)
unnamed: D56.2 (DOUT), TP4.1
unnamed 57: R1.1, TP3.1; also elsewhere on the board

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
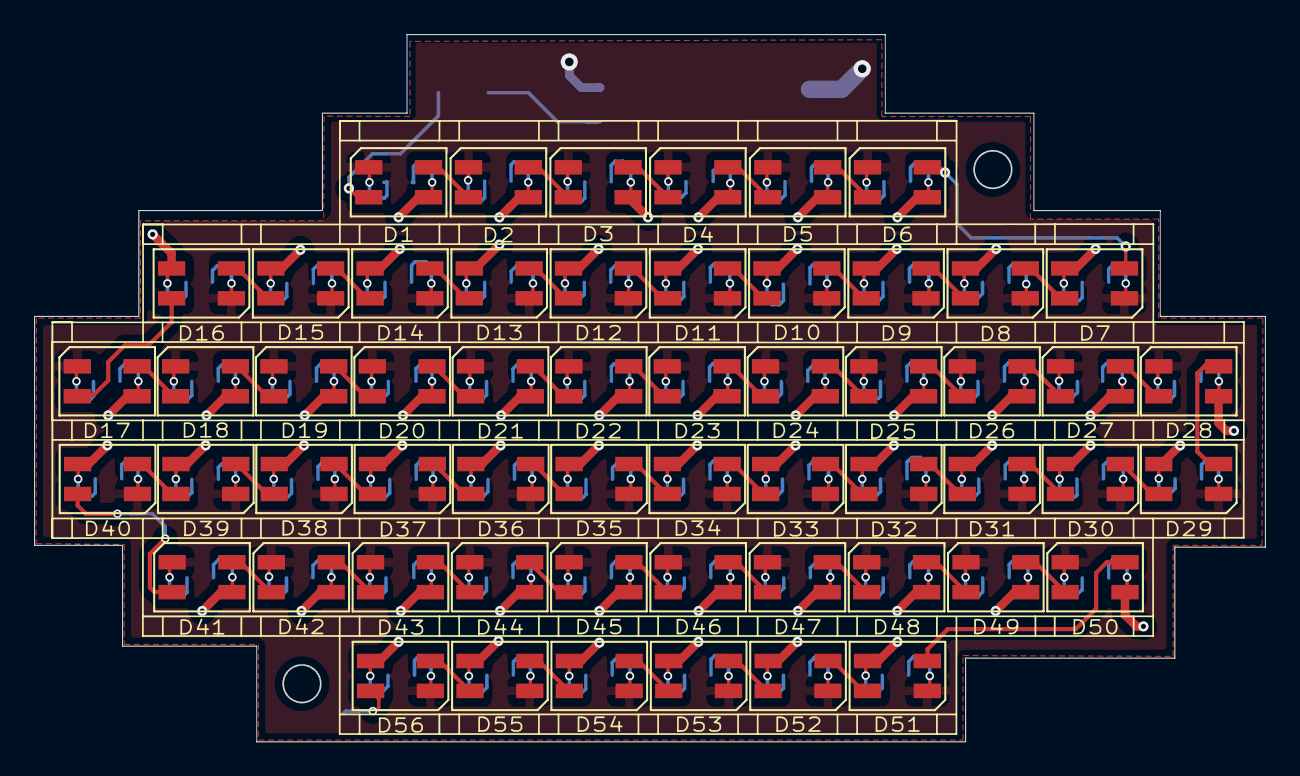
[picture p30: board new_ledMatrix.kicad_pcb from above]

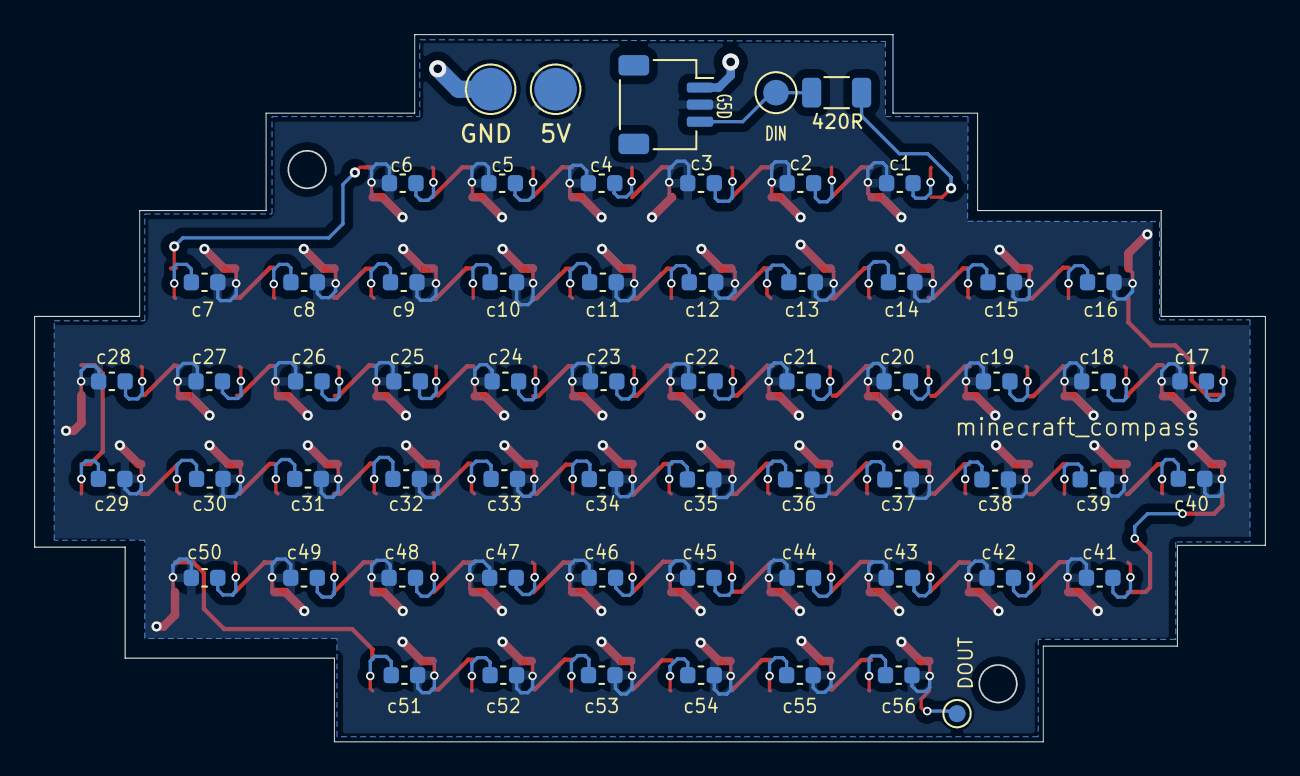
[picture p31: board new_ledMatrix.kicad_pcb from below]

Board: 2 copper layers, 72.1 x 41.4 mm, 118 parts (62 on the bottom side), 60 nets.

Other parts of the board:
G5D: JST_SH_SM03B-SRSS-TB_1x03-1MP_P1.00mm_Horizontal

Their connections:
unnamed 57: G5D.3; also elsewhere on the board

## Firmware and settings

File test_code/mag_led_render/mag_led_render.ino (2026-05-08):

#include <QMC5883LCompass.h>
#include <Adafruit_NeoPixel.h>

// ─────────────────────────────────────────
// LED SETUP
// ─────────────────────────────────────────
#define LED_PIN     9
#define LED_COUNT   56
#define BRIGHTNESS  20

Adafruit_NeoPixel strip(LED_COUNT, LED_PIN, NEO_GRB + NEO_KHZ800);

// ─────────────────────────────────────────
// COLOR DEFINITIONS
// ─────────────────────────────────────────
#define RED      strip.Color(255, 0,   0)
// #define DARK_RED strip.Color(201, 24,  40)
#define DARK_RED strip.Color(255, 0,   0)
#define WHITE    strip.Color(255, 255, 255)
#define OFF      0

// ─────────────────────────────────────────
// LED STATE STRUCT
// ─────────────────────────────────────────
struct LEDState {
    int index;
    uint32_t color;
};

// ─────────────────────────────────────────
// PAGE DEFINITIONS
// ─────────────────────────────────────────
LEDState page0[] = {
    {10,  RED},
    {22,  RED},
    {33,  RED},
    {34,  WHITE},
    {32,  WHITE},
    {45,  WHITE}
};

LEDState page1[] = {
    {9,   RED},
    {23,  RED},
    {22,  RED},
    {33,  RED},
    {34,  WHITE},
    {32,  WHITE},
    {45,  WHITE}
};

LEDState page2[] = {
    {8,   RED},
    {9,   RED},
    {22,  RED},
    {23,  RED},
    {33,  RED},
    {34,  WHITE},
    {32,  WHITE},
    {45,  WHITE},
    {44,  WHITE}
};

LEDState page3[] = {
    {33,  RED},
    {32,  DARK_RED},
    {23,  RED},
    {24,  DARK_RED},
    {8,   RED},
    {7,   DARK_RED},
    {34,  WHITE},
    {44,  WHITE}
};

LEDState page4[] = {
    {33,  RED},
    {32,  DARK_RED},
    {25,  DARK_RED},
    {24,  RED},
    {23,  RED},
    {34,  WHITE},
    {44,  WHITE},
    {43,  WHITE}
};

LEDState page5[] = {
    {23,  RED},
    {24,  RED},
    {25,  RED},
    {26,  DARK_RED},
    {33,  RED},
    {32,  DARK_RED},
    {34,  WHITE},
    {43,  WHITE},
    {44,  WHITE}
};

LEDState page6[] = {
    {26,  RED},
    {25,  RED},
    {24,  RED},
    {31,  DARK_RED},
    {32,  RED},
    {33,  RED},
    {22,  WHITE},
    {34,  WHITE},
    {35,  WHITE},
    {45,  WHITE}
};

LEDState page7[] = {
    {29,  RED},
    {30,  RED},
    {31,  RED},
    {32,  RED},
    {33,  RED},
    {22,  WHITE},
    {34,  WHITE},
    {35,  WHITE},
    {45,  WHITE}
};

LEDState page8[] = {
    {33,  RED},
    {32,  RED},
    {47,  RED},
    {48,  RED},
    {46,  DARK_RED},
    {20,  WHITE},
    {21,  WHITE},
    {34,  WHITE}
};

LEDState page9[] = {
    {33,  RED},
    {32,  RED},
    {46,  RED},
    {47,  RED},
    {48,  DARK_RED},
    {21,  WHITE},
    {20,  WHITE},
    {34,  WHITE},
    {22,  WHITE}
};

LEDState page10[] = {
    {33,  RED},
    {32,  RED},
    {47,  RED},
    {46,  DARK_RED},
    {50,  DARK_RED},
    {22,  WHITE},
    {21,  WHITE},
    {34,  WHITE}
};

LEDState page11[] = {
    {33,  RED},
    {46,  RED},
    {50,  RED},
    {45,  DARK_RED},
    {51,  DARK_RED},
    {21,  WHITE},
    {22,  WHITE},
    {34,  WHITE},
    {32,  WHITE}
};

LEDState page12[] = {
    {22,  WHITE},
    {32,  WHITE},
    {34,  WHITE},
    {33,  RED},
    {45,  RED},
    {52,  DARK_RED}
};

LEDState page13[] = {
    {22,  WHITE},
    {32,  WHITE},
    {34,  WHITE},
    {33,  RED},
    {45,  DARK_RED},
    {44,  RED},
    {53,  RED}
};

LEDState page14[] = {
    {33,  RED},
    {34,  RED},
    {43,  RED},
    {44,  DARK_RED},
    {55,  RED},
    {54,  DARK_RED},
    {32,  WHITE},
    {23,  WHITE}
};

LEDState page15[] = {
    {33,  RED},
    {34,  RED},
    {35,  DARK_RED},
    {43,  RED},
    {44,  DARK_RED},
    {42,  RED},
    {55,  DARK_RED},
    {32,  WHITE},
    {23,  WHITE},
    {24,  WHITE}
};

LEDState page16[] = {
    {33,  RED},
    {34,  RED},
    {35,  DARK_RED},
    {43,  RED},
    {44,  DARK_RED},
    {42,  RED},
    {41,  RED},
    {32,  WHITE},
    {23,  WHITE},
    {24,  WHITE}
};

LEDState page17[] = {
    {33,  RED},
    {34,  RED},
    {35,  RED},
    {43,  DARK_RED},
    {42,  RED},
    {41,  RED},
    {22,  WHITE},
    {32,  WHITE},
    {31,  WHITE},
    {45,  WHITE}
};

LEDState page18[] = {
    {33,  RED},
    {34,  RED},
    {35,  RED},
    {36,  RED},
    {37,  RED},
    {38,  DARK_RED},
    {22,  WHITE},
    {32,  WHITE},
    {31,  WHITE},
    {45,  WHITE}
};

LEDState page19[] = {
    {33,  RED},
    {34,  RED},
    {35,  DARK_RED},
    {20,  RED},
    {19,  RED},
    {18,  RED},
    {22,  WHITE},
    {32,  WHITE},
    {31,  WHITE},
    {45,  WHITE}
};

LEDState page20[] = {
    {33,  RED},
    {34,  DARK_RED},
    {21,  RED},
    {20,  RED},
    {19,  RED},
    {18,  RED},
    {32,  WHITE},
    {46,  WHITE},
    {47,  WHITE}
};

LEDState page21[] = {
    {33,  RED},
    {34,  DARK_RED},
    {21,  RED},
    {20,  RED},
    {19,  DARK_RED},
    {13,  RED},
    {32,  WHITE},
    {46,  WHITE},
    {47,  WHITE}
};

LEDState page22[] = {
    {33,  RED},
    {34,  DARK_RED},
    {21,  RED},
    {20,  RED},
    {12,  RED},
    {13,  RED},
    {32,  WHITE},
    {46,  WHITE},
    {47,  WHITE}
};

LEDState page23[] = {
    {12,  RED},
    {11,  RED},
    {21,  RED},
    {22,  RED},
    {33,  RED},
    {32,  WHITE},
    {46,  WHITE},
    {45,  WHITE},
    {34,  WHITE}
};

LEDState page24[] = {
    {11,  RED},
    {21,  RED},
    {22,  RED},
    {33,  RED},
    {32,  WHITE},
    {45,  WHITE},
    {34,  WHITE}
};

// ─────────────────────────────────────────
// PAGE REGISTRY
// ─────────────────────────────────────────
LEDState* pages[] = {
    page0,  page1,  page2,  page3,  page4,
    page5,  page6,  page7,  page8,  page9,
    page10, page11, page12, page13, page14,
    page15, page16, page17, page18, page19,
    page20, page21, page22, page23, page24
};

int pageSizes[] = {
    sizeof(page0)  / sizeof(page0[0]),
    sizeof(page1)  / sizeof(page1[0]),
    sizeof(page2)  / sizeof(page2[0]),
    sizeof(page3)  / sizeof(page3[0]),
    sizeof(page4)  / sizeof(page4[0]),
    sizeof(page5)  / sizeof(page5[0]),
    sizeof(page6)  / sizeof(page6[0]),
    sizeof(page7)  / sizeof(page7[0]),
    sizeof(page8)  / sizeof(page8[0]),
    sizeof(page9)  / sizeof(page9[0]),
    sizeof(page10) / sizeof(page10[0]),
    sizeof(page11) / sizeof(page11[0]),
    sizeof(page12) / sizeof(page12[0]),
    sizeof(page13) / sizeof(page13[0]),
    sizeof(page14) / sizeof(page14[0]),
    sizeof(page15) / sizeof(page15[0]),
    sizeof(page16) / sizeof(page16[0]),
    sizeof(page17) / sizeof(page17[0]),
    sizeof(page18) / sizeof(page18[0]),
    sizeof(page19) / sizeof(page19[0]),
    sizeof(page20) / sizeof(page20[0]),
    sizeof(page21) / sizeof(page21[0]),
    sizeof(page22) / sizeof(page22[0]),
    sizeof(page23) / sizeof(page23[0]),
    sizeof(page24) / sizeof(page24[0]),
};

// ─────────────────────────────────────────
// SHOW PAGE FUNCTION
// ─────────────────────────────────────────
void showPage(int pageIndex) {

    for (int i = 0; i < LED_COUNT; i++) {
        strip.setPixelColor(i, OFF);
    }

    LEDState* page = pages[pageIndex];
    int size = pageSizes[pageIndex];

    for (int i = 0; i < size; i++) {
        strip.setPixelColor(page[i].index, page[i].color);
    }

    strip.show();
}

// ─────────────────────────────────────────
// HEADING TO PAGE
// 360° / 25 pages = 14.4° per page
// Page 0 centered on North (0°)
// ─────────────────────────────────────────
int headingToPage(float heading) {

    // shift by half-page width
    heading += 7.2;

    // wrap around
    if (heading >= 360.0)
        heading -= 360.0;

    int page = (int)(heading / 14.4);

    // safety clamp
    if (page > 24) page = 24;
    if (page < 0)  page = 0;

    return page;
}

// ─────────────────────────────────────────
// COMPASS
// ─────────────────────────────────────────
QMC5883LCompass compass;

int lastPage = -1;
float PAGE_WIDTH = 14.4;
float HYSTERESIS = 0.0; // degrees

// ─────────────────────────────────────────
// SETUP
// ─────────────────────────────────────────
void setup() {

    Serial.begin(115200);

    strip.begin();
    strip.setBrightness(BRIGHTNESS);
    strip.show();

    compass.init();

    compass.setCalibrationOffsets(-279.00, 2503.00, 1727.00);
    compass.setCalibrationScales(1.16, 0.79, 1.14);


    delay(100);

    Serial.println("Compass ready");
}

// ─────────────────────────────────────────
// LOOP
// ─────────────────────────────────────────
void loop() {

    compass.read();

    int x = compass.getX();
    int y = compass.getY();

    float heading = atan2((float)y, (float)x) * 180.0 / PI;

    // reverse direction
    heading = 360.0 - heading;

    if (heading < 0)
        heading += 360.0;

    if (heading >= 360.0)
        heading -= 360.0;

    int page;

    // first run
    if (lastPage == -1) {

        page = headingToPage(heading);

    } else {

        page = lastPage;

        // center of current page
        float center = lastPage * PAGE_WIDTH;

        // compensate for centered north
        center -= 7.2;

        if (center < 0)
            center += 360.0;

        // signed shortest angular difference
        float diff = heading - center;

        if (diff > 180) diff -= 360;
        if (diff < -180) diff += 360;

        // hysteresis thresholds
        if (diff > (PAGE_WIDTH / 2 + HYSTERESIS)) {

            page = (lastPage + 1) % 25;

        } else if (diff < -(PAGE_WIDTH / 2 + HYSTERESIS)) {

            page = (lastPage - 1 + 25) % 25;
        }
    }

    // redraw only if page changed
    if (page != lastPage) {

        showPage(page);

        lastPage = page;

        Serial.print("Heading: ");
        Serial.print((int)heading);
        Serial.print((char)176);

        Serial.print("  Page: ");
        Serial.println(page);
    }

    delay(50);
}

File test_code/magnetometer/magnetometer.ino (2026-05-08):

#include <QMC5883LCompass.h>

QMC5883LCompass compass;

void setup() {
    Serial.begin(115200);
    compass.init();
    compass.setCalibrationOffsets(-122.00, -67.00, 119.00);
    compass.setCalibrationScales(0.95, 0.99, 1.06);
    delay(100);
    Serial.println("QMC5883L Heading (0-359)");
    Serial.println("Rotate sensor flat on table");
    Serial.println("─────────────────────────");
}

void loop() {
    compass.read();

    int x = compass.getX();
    int y = compass.getY();

    // calculate heading from X and Y only
    float heading = atan2((float)y, (float)x) * 180.0 / PI;

    // normalize to 0-359
    if (heading < 0)    heading += 360.0;
    if (heading >= 360) heading -= 360.0;

    // cast to int for clean 0-359 output
    int headingInt = (int)heading;

    // cardinal direction
    String direction;
    if      (headingInt < 22)  direction = "N";
    else if (headingInt < 67)  direction = "NE";
    else if (headingInt < 112) direction = "E";
    else if (headingInt < 157) direction = "SE";
    else if (headingInt < 202) direction = "S";
    else if (headingInt < 247) direction = "SW";
    else if (headingInt < 292) direction = "W";
    else if (headingInt < 337) direction = "NW";
    else                       direction = "N";

    Serial.print("Heading: ");
    Serial.print(headingInt);
    Serial.print((char)176);
    Serial.print("  ");
    Serial.println(direction);

    delay(100);
}

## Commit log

2025-09-14 Ver_6 top added
    [minecraftCompassVer.3-top(resized_body).stl]
2025-09-25 added DOUT in PCB
    [led_matrix.FCStd, minecraftCompassVer.3-bottom.stl, minecraftCompassVer.3-top.stl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]
2025-09-27 added DOUT to pcb
    [new_ledMatrix.kicad_pcb]
2025-09-29 via holes moved
    [new_ledMatrix.kicad_pcb]
2025-10-01 via holes alligned
    [new_ledMatrix.kicad_pcb]
2025-10-06 final silkscreen imporved with no drs error
    [new_ledMatrix-B_Cu.gbr, new_ledMatrix-B_Mask.gbr, new_ledMatrix-B_Paste.gbr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]
2025-10-30 ver.8 of STL(Final)
    [minecraftCompass_bottom(Ver.4).stl, minecraftCompass_top(Ver.4).stl]
2026-01-02 arbitrary update
    [minecraftCompassVer.3.FCStd, minecraftCompass_top(Ver.4).stl]
2026-02-16 jst connector added
    [new_ledMatrix.kicad_pcb, new_ledMatrix.kicad_sch]
2026-03-17 extended grills for better led squarish lighting
    [minecraftCompassVer.3.FCStd]
2026-04-02 added funnels to the LED grid(space between each grid square is 0.1mm)
    [mincraft_compass.FCStd, minecraftCompassVer.2.FCStd, minecraftCompassVer.3.FCStd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]
2026-04-26 added test-code dir and the frames
2026-05-06 Cleanup: keep single source STL/KiCad files; remove duplicates
    [led_matrix.FCStd, mincraft_compass-bottom_scaled_copy.stl, mincraft_compass-top_scaled_copy.stl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]
2026-05-06 Update README.md: remove versioned-file guidance, add structure table and print instructions
    Agent-Logs-Url: https://github.com/lucky-mango/minecraft_compass/sessions/5c0626f4-daf4-4494-bd9d-0f26a99ae4b4
2026-05-08 mag_led.ino and magnetometer.ino added in test_code/
2026-05-19 upadted pcb to ver7
    [new_ledMatrix.kicad_pcb, new_ledMatrix.kicad_sch]
2026-05-20 pcb hole placement fixed, also added it in freecad model view
    [SM03B-SRSS-TB (LF)(SN).STEP, SMD WS2812B Mini.step, minecraftCompassVer.4.FCStd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]
2026-05-21 added skrew stand offs in free cad model for pcb in top plate
    [minecraftCompassVer.4.FCStd]
2026-05-21 exported stl files for the top and bottom plate
    [GY-273 v6.step, MPU6050 v2.step, MPU6050 v2.stl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]
2026-05-27 in /FreeCAD changed the topPlate ecah pixel's bezzel: 0.1mm->0.2mm and screen thickness: 0.3mm -> 1.0mm, also exported both models as stl in /3dmodels/compass_case
    [minecraftCompassVer.4-bottomPlate.stl, minecraftCompassVer.4-topPlate.stl, minecraftCompassVer.4.FCStd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]
2026-05-29 3d model top plate pcb screw hole 5H->6H
    [minecraftCompassVer.4-topPlate.stl, minecraftCompassVer.4.FCStd]
2026-06-08 skrew hole in top plate -tolerance increased
    [LED_matrix_ver7.step, minecraftCompassVer.4-topPlate.stl, minecraftCompassVer.4.FCStd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]
2026-06-11 custom clearance on the bottom_plate for mpu6050 and hmc58833L skrew holes
    [minecraftCompassVer.4-bottomPlate.stl, minecraftCompassVer.4.FCStd]
2026-06-16 added daughter a daughterbaord in /Kicad and create the buck boost converter schematic only
    [XEL4030-102MEC.step, daughter_board.kicad_pcb, daughter_board.kicad_sch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]
2026-06-17 in /Kicad/daughterboard added the mpu6050 schematic in the daughter board
    [daughter_board.kicad_sch]
2026-06-18 added datasheets, 3d models and alsocreated the schematic for qmc5883L
    [EDI2CAP.CFG, QMC5883L.PcbLib, QMC5883L.SchLib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]
2026-06-18 kicad schematic finished for the daughter board (initial design)
    [daughter_board.kicad_sch]
2026-06-18 added power connector to the schematic, next step is to make the footprint
    [JST_PH_S2B-PH-SM4-TB_1x02-1MP_P2.00mm_Horizontal.step, daughter_board.kicad_sch]
2026-06-21 completed new freecad base_plate and the KiCAD pcb design
    [HMC5883L-TR.STEP, MPU-6050C.STEP, daughter_board.kicad_pcb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]
2026-06-21 added a new stl file for base_plate for m2x2mm heat inserts
    [minecraftCompassVer.4-bottomPlate.stl, minecraftCompassVer.4-bottom_plate(heat_insert-M2x2mm).stl, minecraftCompassVer.4-bottom_plate.stl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]
2026-06-23 in /FreeCAD model added skrews and the final daughter board,also in /Kicad added voletage divider in daughter board
    [TPS61023DRLR.STEP, XEL4030-102MEC--3DModel-STEP-269445.STEP, daughter_board.kicad_pcb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]
2026-06-23 in /KiCAD changed the silkscreen from actual values to reference notations
    [daughter_board.kicad_pcb, daughter_board.step]
2026-06-25 clean ip in /KiCAD of old gerber .zip files
2026-06-28 in /FreeCAD added the deposed c.s. also added the stl file for the same in /3dModels
    [daughter_board.step, minecraftCompassVer.4-bottom_plate(heat_inserts of m2x2mm).stl, minecraftCompassVer.4.FCStd]
2026-07-17 in the pcb of daughter board, change the ground pour plane from top to bottom and power plane from bottom to top
    [assembly.FCStd, daughter_board.kicad_pcb, minecraftCompassVer.4.FCStd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]
2026-07-17 changed the min via hole so that min via hole=0.3mm
    [daughter_board.kicad_pcb]
2026-07-21 changed the readme images
    [daughter_board.kicad_pcb]
2026-07-26 added a 3d model of the bottom with heat inserts that are 2mm deep
    [minecraftCompassVer.4-bottom_plate(heat_inserts of m2x2mm,OD-3.1mm).stl]
2026-07-28 due to clearence issue of the power connecter in the daughter baord- changed the 2mm jst to 1mm jst, also updated the 3d model in freecad
    [BOM.csv, GY-273 v6.step, daughter_board-v2.step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]
2026-07-29 touch on the daughter board silkscreen
    [daughter_board.kicad_pcb]
2026-08-02 added new stl files
    [minecraftCompassVer.4-bottom_plate(4mm_gridBezzel).stl, minecraftCompassVer.4-bottom_plate(lowered_daughterBoard,heatinserts-2mm_deep).stl]
2026-08-02 changed the schematic and pads of C and R to non-handsolder ones
    [daughter_board.kicad_pcb, daughter_board.kicad_sch]
2026-09-26 reversed the polatrity of the power plug in the daughter board
    [daughter_board.csv, daughter_board.kicad_pcb, daughter_board.kicad_sch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]
